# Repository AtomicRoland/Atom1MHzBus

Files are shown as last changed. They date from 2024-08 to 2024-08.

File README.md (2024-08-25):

This KiCAD project is an 1 MHz bus interface for the Acorn Atom and Acorn System series computers. It provides both 1 MHz bus and BBC Micro compatible User Port. The 6522 
of the Atom or System CPU board is used for the User Port interface. The AB connector is placed on the board in a way that you can easily swap both rows. It might be necessary 
to shorten the board to the printed line at the solder side, next to the AB connector.

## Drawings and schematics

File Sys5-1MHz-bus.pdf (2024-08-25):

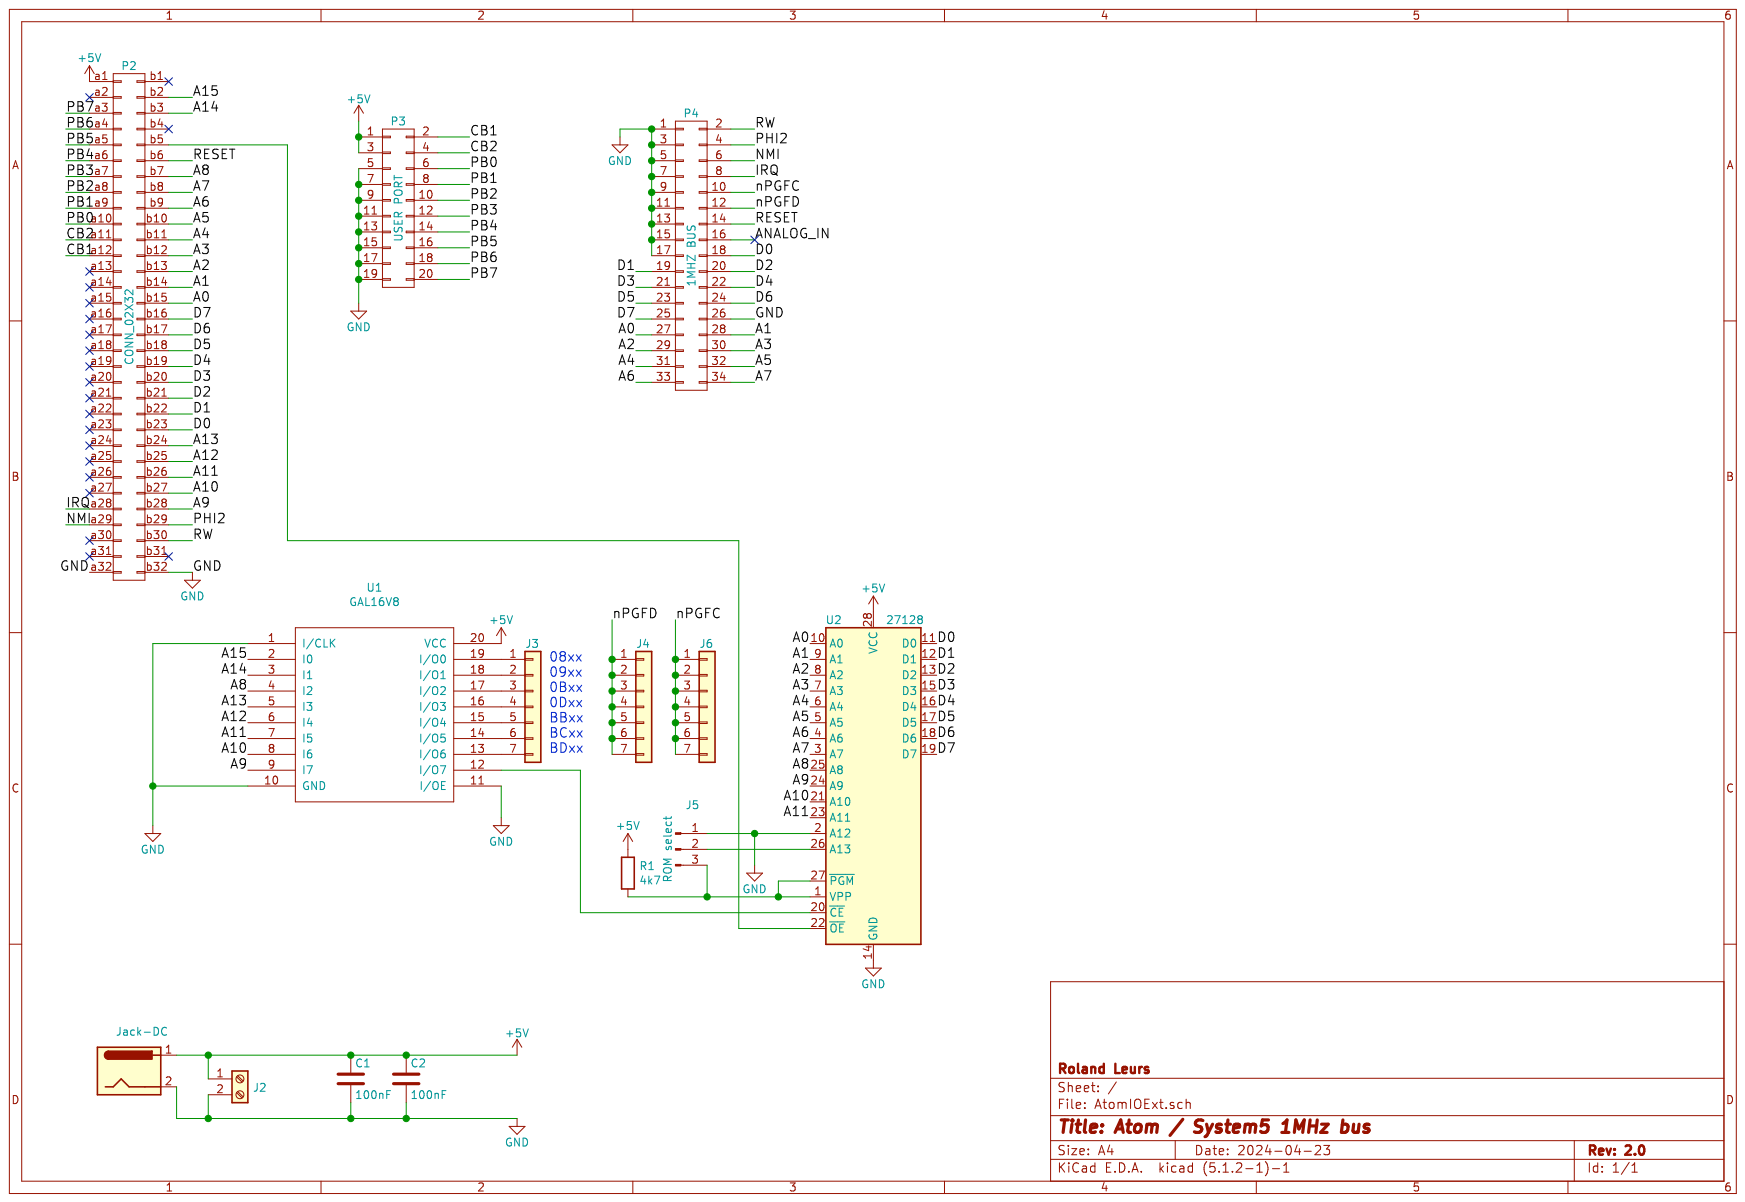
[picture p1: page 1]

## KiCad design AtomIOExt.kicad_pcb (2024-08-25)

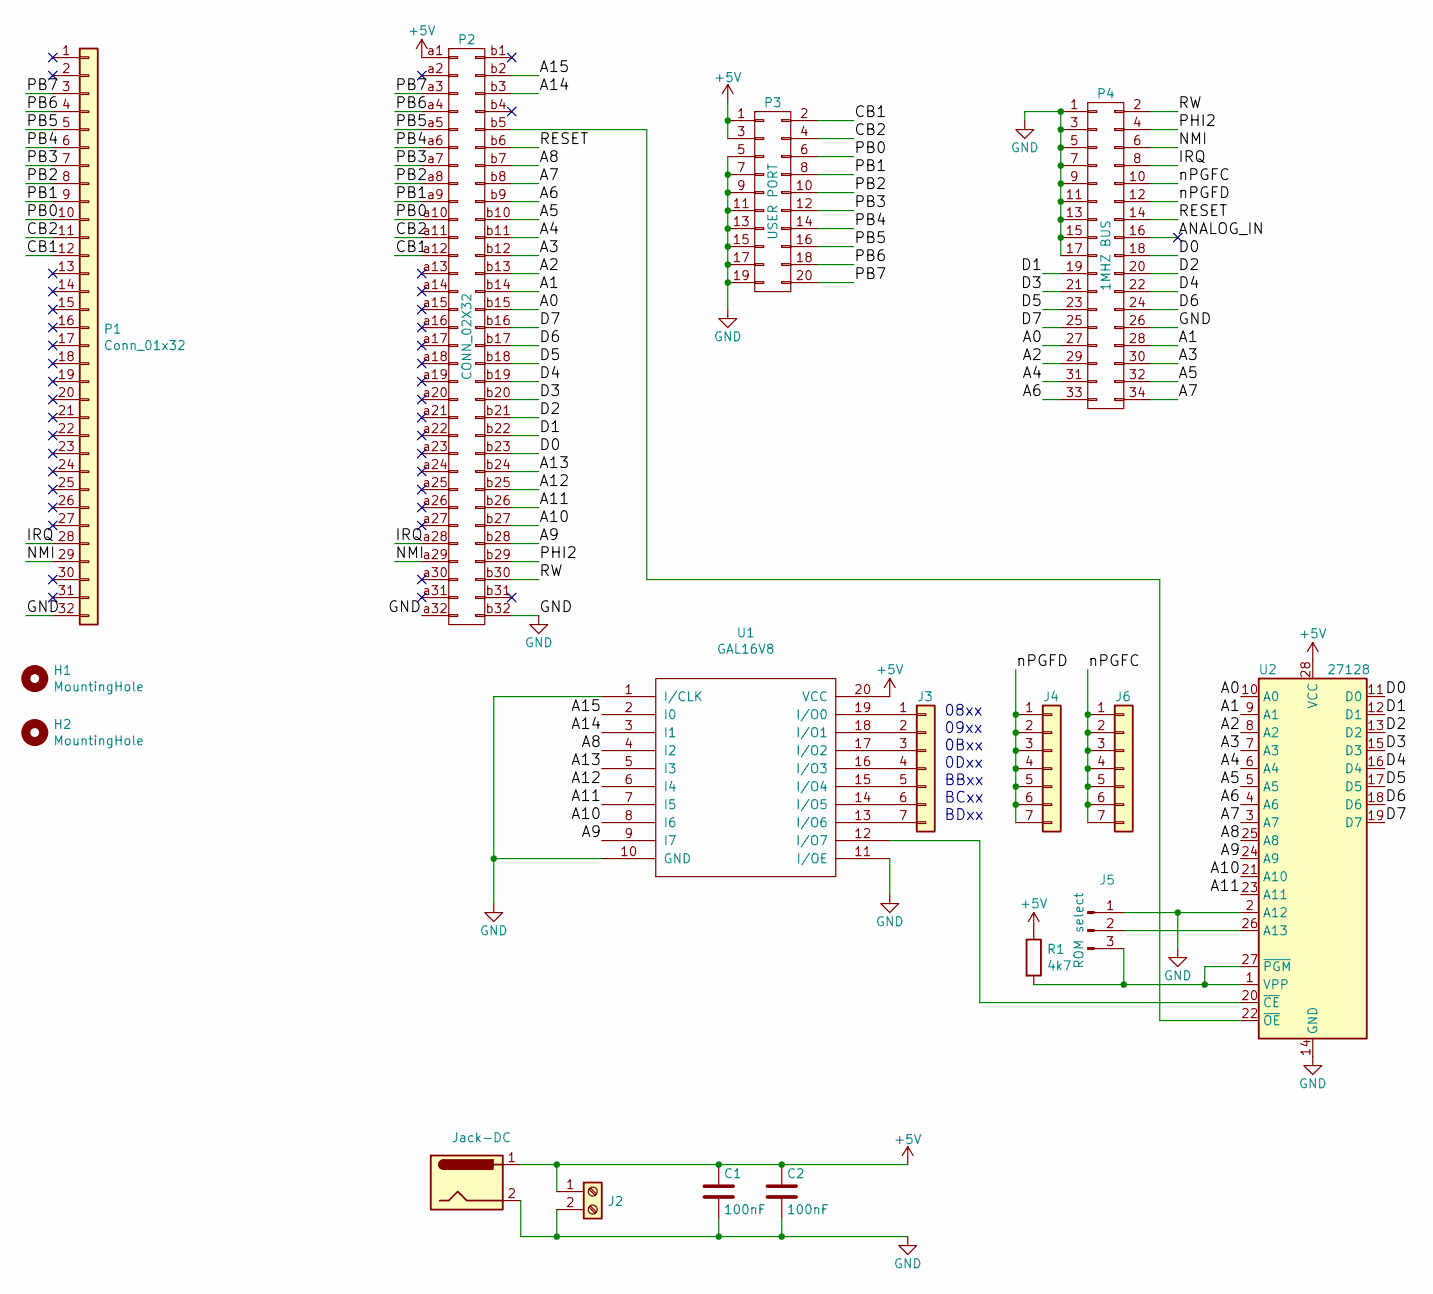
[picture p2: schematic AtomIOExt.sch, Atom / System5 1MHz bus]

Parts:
C1, C2: 100nF; C_Disc_D5.0mm_W2.5mm_P5.00mm
H1, H2: MountingHole; MountingHole_4.3mm_M4
J1: Jack-DC; BarrelJack_Horizontal
J2: Screw_Terminal_01x02; TerminalBlock_MetzConnect_Type101_RT01602HBWC_1x02_P5.08mm_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
J3, J4, J6: Conn_01x07; PinHeader_1x07_P2.54mm_Vertical
J5: ROM select; PinHeader_1x03_P2.54mm_Vertical
P1: Conn_01x32; PinHeader_1x32_P2.54mm_Vertical
P2: CONN_02X32; DIN41612_B_2x32_Horizontal
P3: USER PORT; IDC-Header_2x10_P2.54mm_Vertical
P4: 1MHZ BUS; IDC-Header_2x17_P2.54mm_Vertical
R1: 4k7; R_Axial_DIN0411_L9.9mm_D3.6mm_P12.70mm_Horizontal
U1: GAL16V8; DIP-20_W7.62mm_LongPads
U2: 27128; DIP-28_W15.24mm

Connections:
+5V: C1.1, C2.1, J1.1, J2.1, P2.a1, P3.1, P3.3, R1.1, U1.20 (VCC), U2.28 (VCC)
/A0: P2.b15, P4.27, U2.10 (A0)
/A1: P2.b14, P4.28, U2.9 (A1)
/A2: P2.b13, P4.29, U2.8 (A2)
/A3: P2.b12, P4.30, U2.7 (A3)
/A4: P2.b11, P4.31, U2.6 (A4)
/A5: P2.b10, P4.32, U2.5 (A5)
/A6: P2.b9, P4.33, U2.4 (A6)
/A7: P2.b8, P4.34, U2.3 (A7)
/A8: P2.b7, U1.4 (I2), U2.25 (A8)
/A9: P2.b28, U1.9 (I7), U2.24 (A9)
/A10: P2.b27, U1.8 (I6), U2.21 (A10)
/A11: P2.b26, U1.7 (I5), U2.23 (A11)
/A12: P2.b25, U1.6 (I4)
/A13: P2.b24, U1.5 (I3)
/A14: P2.b3, U1.3 (I1)
/A15: P2.b2, U1.2 (I0)
/CB1: P1.12, P2.a12, P3.2
/CB2: P1.11, P2.a11, P3.4
/D0: P2.b23, P4.18, U2.11 (D0)
/D1: P2.b22, P4.19, U2.12 (D1)
/D2: P2.b21, P4.20, U2.13 (D2)
/D3: P2.b20, P4.21, U2.15 (D3)
/D4: P2.b19, P4.22, U2.16 (D4)
/D5: P2.b18, P4.23, U2.17 (D5)
/D6: P2.b17, P4.24, U2.18 (D6)
/D7: P2.b16, P4.25, U2.19 (D7)
/IRQ: P1.28, P2.a28, P4.8
/NMI: P1.29, P2.a29, P4.6
/PB0: P1.10, P2.a10, P3.6
/PB1: P1.9, P2.a9, P3.8
/PB2: P1.8, P2.a8, P3.10
/PB3: P1.7, P2.a7, P3.12
/PB4: P1.6, P2.a6, P3.14
/PB5: P1.5, P2.a5, P3.16
/PB6: P1.4, P2.a4, P3.18
/PB7: P1.3, P2.a3, P3.20
/PHI2: P2.b29, P4.4
/RESET: P2.b6, P4.14
/RW: P2.b30, P4.2
/nPGFC: J6.1, J6.2, J6.3, J6.4, J6.5, J6.6, J6.7, P4.10
/nPGFD: J4.1, J4.2, J4.3, J4.4, J4.5, J4.6, J4.7, P4.12
GND: C1.2, C2.2, J1.2, J2.2, J5.1, P1.32, P2.a32, P2.b32, P3.5, P3.7, P3.9, P3.11, P3.13, P3.15, P3.17, P3.19, P4.1, P4.3, P4.5, P4.7, P4.9, P4.11, P4.13, P4.15, P4.17, P4.26, U1.1 (I/CLK), U1.10 (GND), U1.11 (I/OE), U2.2 (A12), U2.14 (GND)
unnamed: J3.1, U1.19 (I/O0)
unnamed: J3.2, U1.18 (I/O1)
unnamed: J3.3, U1.17 (I/O2)
unnamed: J3.4, U1.16 (I/O3)
unnamed: J3.5, U1.15 (I/O4)
unnamed: J3.6, U1.14 (I/O5)
unnamed: J3.7, U1.13 (I/O6)
unnamed: J5.2, U2.26 (A13)
unnamed: J5.3, R1.2, U2.1 (VPP), U2.27 (~PGM)
unnamed: P2.b5, U2.22 (~OE)
unnamed: U1.12 (I/O7), U2.20 (~CE)

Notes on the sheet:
08xx 09xx 0Bxx 0Dxx BBxx BCxx BDxx

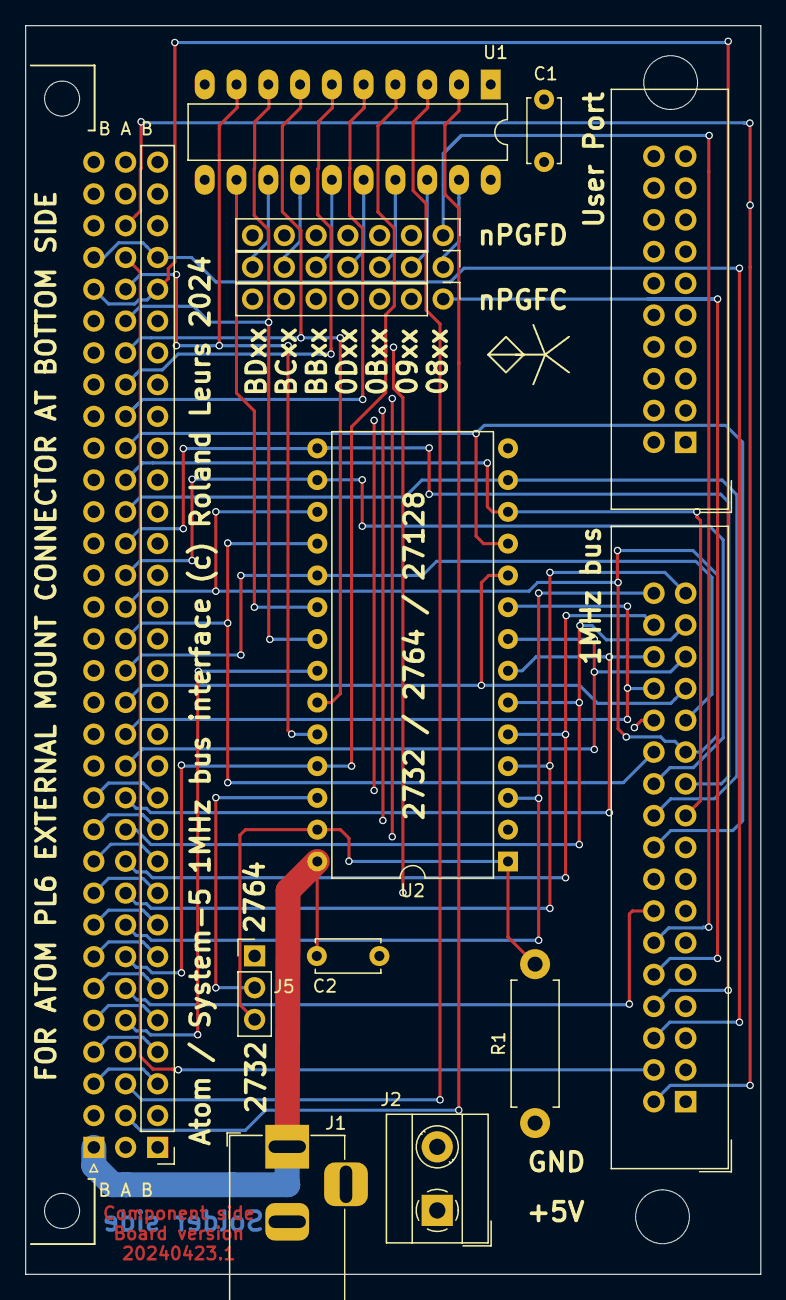
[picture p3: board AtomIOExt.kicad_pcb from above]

Board: 4 copper layers, 58.8 x 99.8 mm, 17 parts (0 on the bottom side), 54 nets.
